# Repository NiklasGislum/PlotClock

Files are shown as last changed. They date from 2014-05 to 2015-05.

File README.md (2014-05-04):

PlotClock
=========

Fork of the plotclock optimized for better manfucaturability and for the available whiteboard markers.

* Larger material ring around screw holes for greater strength
* Larger holes for servo screws in the spacer plates.
* Claw now fits steadler whiteboard markers.
* M3 holes now accept 16 mm screws, because that what we had in stock.

TODO: 

* Go back to using filled shape for the servo-horn holes.
* Add text labels to each junction to make it easier to write an assembly manual.

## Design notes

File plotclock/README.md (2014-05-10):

plotclock
=========

plotclock

a clock that plots time

What you need
-------------
* Lasercutter or 3D Printer

* one Arduino (e.g. uno)

* three RC-Servos Mini (e.g. Tower Pro 9g)

* one whiteboard marker, dry eerasable (e.g. WB SL DRYWIPE MARKER)

* Screws, nuts, washers M3 and a tap for cutting M3.

Assembly
--------

See: http://www.thingiverse.com/thing:248009/#instructions

--

this actually is my first git project, so merging, forks etc. is still new to me and could take some time

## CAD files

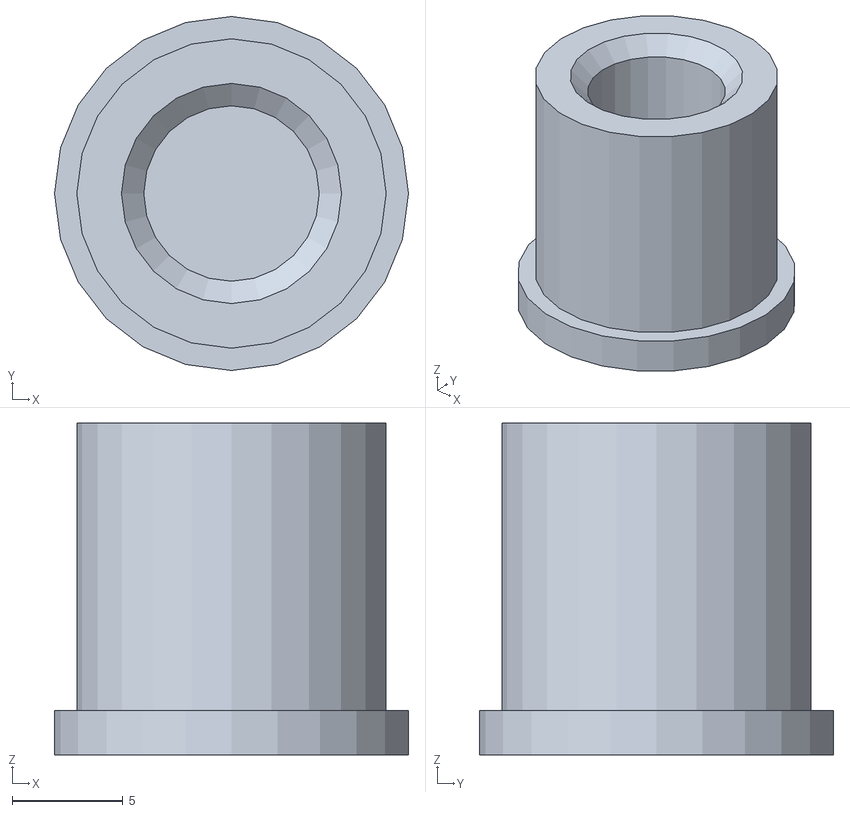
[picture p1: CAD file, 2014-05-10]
plotclock/swee.stl
16.0 x 16.0 x 15.0

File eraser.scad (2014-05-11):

difference(){
 union(){
  cylinder( r=7, h=8, $fn=100);
  cylinder( r=10, h=1, $fn=100);
  translate(v = [0, 0, 1]) {
  	cylinder( r1=10, r2=7, h=3, $fn=100);
  }
 }

 translate(v = [0, 0, 0.5]) {
  cylinder( r=2.25, h=8, $fn=100);
 }
 translate(v = [0, 0, 6]) {
  cylinder( r1=2.25, r2=6, h=3, $fn=100);
 }
}
 

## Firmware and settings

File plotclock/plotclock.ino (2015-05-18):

// Plotclock
// cc - by Johannes Heberlein 2014
// v 1.02
// thingiverse.com/joo   wiki.fablab-nuernberg.de
// units: mm; microseconds; radians
// origin: bottom left of drawing surface
// time library see http://playground.arduino.cc/Code/time 
// RTC  library see http://playground.arduino.cc/Code/time 
//               or http://www.pjrc.com/teensy/td_libs_DS1307RTC.html  
// Change log:
// 1.01  Release by joo at https://github.com/9a/plotclock
// 1.02  Additional features implemented by Dave:
//       - added ability to calibrate servofaktor seperately for left and right servos
//       - added code to support DS1307, DS1337 and DS3231 real time clock chips
//       - see http://www.pjrc.com/teensy/td_libs_DS1307RTC.html for how to hook up the real time clock 

// delete or mark the next line as comment if you don't need these
//#define REALTIMECLOCK    // enable real time clock

// delete or mark the next line as comment if you don't need these
#include <Stepper.h>
#define ALARM    // enable the alarm
#define SERIALOUTPUT // outputs the servor values to serial
// Create a file called calibration.h with the robot-specific values
#include "calibration.h"

/*
This is the content that your calibration.h file should have:
//#define CALIBRATION      // enable calibration mode

#define SERVOFAKTORLEFT 590
#define SERVOFAKTORRIGHT 600

// Zero-position of left and right servo
// When in calibration mode, adjust the NULL-values so that the servo arms are at all times parallel
// either to the X or Y axis
#define SERVOLEFTNULL 2320
#define SERVORIGHTNULL 1010


#define LIFT0 1150 // on drawing surface
#define LIFT1 825  // between numbers
#define LIFT2 725  // going towards sweeper

*/



// GPIO pins that the servos are connected to:
#define SERVOPINLIFT  6
#define SERVOPINLEFT  5
#define SERVOPINRIGHT 4

// lift positions of lifting servo
/*
#define LIFT0 1000 // on drawing surface
#define LIFT1 925  // between numbers
#define LIFT2 725  // going towards sweeper
*/

// speed of liftimg arm, higher is slower
#define LIFTSPEED 1500

// length of arms
#define L1 35
#define L2 55.1
#define L3 13.2

// origin points of left and right servo 
#define O1X 22
#define O1Y -25
#define O2X 48
#define O2Y -25

#define COLON 11

#define PARK_X 72
#define PARK_Y 42



#include <Time.h> // see http://playground.arduino.cc/Code/time 
#include <Servo.h>

#ifdef REALTIMECLOCK
// for instructions on how to hook up a real time clock,
// see here -> http://www.pjrc.com/teensy/td_libs_DS1307RTC.html
// DS1307RTC works with the DS1307, DS1337 and DS3231 real time clock chips.
// Please run the SetTime example to initialize the time on new RTC chips and begin running.

  #include <Wire.h>
  #include <DS1307RTC.h> // see http://playground.arduino.cc/Code/time    
#endif

#ifdef ALARM
	#include <TimeAlarms.h>
#endif

int servoLift = 1500;

Servo servo1;  // 
Servo servo2;  // 
Servo servo3;  // 

volatile double lastX = PARK_X;
volatile double lastY = PARK_Y;

 int servo1ValRad;
 int servo2ValRad;
 int servo3ValRad;

int last_min = 0;

void setup() 
{ 
#ifdef REALTIMECLOCK
  Serial.begin(115200);
  //while (!Serial) { ; } // wait for serial port to connect. Needed for Leonardo only

  // Set current time only the first to values, hh,mm are needed  
  tmElements_t tm;
  if (RTC.read(tm)) 
  {
    setTime(tm.Hour,tm.Minute,tm.Second,tm.Day,tm.Month,tm.Year);
    Serial.println("DS1307 time is set OK.");
  } 
  else 
  {
    if (RTC.chipPresent())
    {
      Serial.println("DS1307 is stopped.  Please run the SetTime example to initialize the time and begin running.");
    } 
    else 
    {
      Serial.println("DS1307 read error!  Please check the circuitry.");
    } 
    // Set current time only the first to values, hh,mm are needed
    setTime(19,38,0,0,0,0);
  }
#else  
  // Set current time only the first to values, hh,mm are needed
  setTime(10,01,0,0,0,0);
#endif

#ifdef ALARM
  Alarm.alarmRepeat(10, 8, 0, alarmAction);
#endif

#ifdef SERIALOUTPUT
  Serial.begin(9600);
#endif

  servoLift = LIFT0;
  lift(2);
  servo1.attach(SERVOPINLIFT);  //  lifting servo
  delay(1000); // Wait for the pen to be raised
  servo2.attach(SERVOPINLEFT);  //  left servo
  servo3.attach(SERVOPINRIGHT);  //  right servo
 
  lift(2);
  drawTo(PARK_X, PARK_Y);
  lift(0);

  delay(1000);
} 

void loop() 
{ 

  
#ifdef CALIBRATION
  // Servohorns will have 90° between movements, parallel to x and y axis

  drawTo(-3, 29.2);
  delay(500);
  drawTo(74.1, 28);
  delay(500);


#else 


  int i = 0;
  if (last_min != minute()) {

	  if (!servo1.attached()) servo1.attach(SERVOPINLIFT);
	  if (!servo2.attached()) servo2.attach(SERVOPINLEFT);
	  if (!servo3.attached()) servo3.attach(SERVOPINRIGHT);

    lift(0);

    hour();
    while ((i+1)*10 <= hour())
    {
      i++;
    }

    erase();
    lift(2);

    drawChar(5, 25, i, 0.9);
    drawChar(19, 25, (hour()-i*10), 0.9);
    drawChar(28, 25, COLON, 0.9);

    i=0;
    while ((i+1)*10 <= minute())
    {
      i++;
    }
    drawChar(34, 25, i, 0.9);
    drawChar(48, 25, (minute()-i*10), 0.9);
    lift(2);
    drawTo(PARK_X, PARK_Y);
    lift(0);
    last_min = minute();

    servo1.detach();
    servo2.detach();
    servo3.detach();
  }

#endif

} 

// Writing numeral with bx by being the bottom left originpoint. Scale 1 equals a 20 mm high font.
// The structure follows this principle: move to first startpoint of the numeral, lift down, draw numeral, lift up
void drawChar(float bx, float by, int num, float scale) {
  switch (num) {

  case 0:
    drawTo(bx + 12 * scale, by + 6 * scale);
    lift(0);
    bogenGZS(bx + 7 * scale, by + 10 * scale, 10 * scale, -0.8, 6.7, 0.5);
    lift(1);
    break;
  case 1:

    drawTo(bx + 3 * scale, by + 15 * scale);
    lift(0);
    drawTo(bx + 10 * scale, by + 20 * scale);
    drawTo(bx + 10 * scale, by + 0 * scale);
    lift(1);
    break;
  case 2:
    drawTo(bx + 2 * scale, by + 12 * scale);
    lift(0);
    bogenUZS(bx + 8 * scale, by + 14 * scale, 6 * scale, 3, -0.8, 1);
    drawTo(bx + 1 * scale, by + 0 * scale);
    drawTo(bx + 12 * scale, by + 0 * scale);
    lift(1);
    break;
  case 3:
    drawTo(bx + 2 * scale, by + 17 * scale);
    lift(0);
    bogenUZS(bx + 5 * scale, by + 15 * scale, 5 * scale, 3, -2, 1);
    bogenUZS(bx + 5 * scale, by + 5 * scale, 5 * scale, 1.57, -3, 1);
    lift(1);
    break;
  case 4:
    drawTo(bx + 10 * scale, by + 0 * scale);
    lift(0);
    drawTo(bx + 10 * scale, by + 20 * scale);
    drawTo(bx + 2 * scale, by + 6 * scale);
    drawTo(bx + 12 * scale, by + 6 * scale);
    lift(1);
    break;
  case 5:
    drawTo(bx + 2 * scale, by + 5 * scale);
    lift(0);
    bogenGZS(bx + 5 * scale, by + 6 * scale, 6 * scale, -2.5, 2, 1);
    drawTo(bx + 5 * scale, by + 20 * scale);
    drawTo(bx + 12 * scale, by + 20 * scale);
    lift(1);
    break;
  case 6:
    drawTo(bx + 2 * scale, by + 10 * scale);
    lift(0);
    bogenUZS(bx + 7 * scale, by + 6 * scale, 6 * scale, 2, -4.4, 1);
    drawTo(bx + 11 * scale, by + 20 * scale);
    lift(1);
    break;
  case 7:
    drawTo(bx + 2 * scale, by + 20 * scale);
    lift(0);
    drawTo(bx + 12 * scale, by + 20 * scale);
    drawTo(bx + 2 * scale, by + 0);
    lift(1);
    break;
  case 8:
    drawTo(bx + 5 * scale, by + 10 * scale);
    lift(0);
    bogenUZS(bx + 5 * scale, by + 15 * scale, 5 * scale, 4.7, -1.6, 1);
    bogenGZS(bx + 5 * scale, by + 5 * scale, 5 * scale, -4.7, 2, 1);
    lift(1);
    break;

  case 9:
    drawTo(bx + 9 * scale, by + 11 * scale);
    lift(0);
    bogenUZS(bx + 7 * scale, by + 15 * scale, 5 * scale, 4, -0.5, 1);
    drawTo(bx + 5 * scale, by + 0);
    lift(1);
    break;

  case COLON:
    drawTo(bx + 5 * scale, by + 15 * scale);
    lift(0);
    bogenGZS(bx + 5 * scale, by + 15 * scale, 0.1 * scale, 1, -1, 1);
    lift(1);
    drawTo(bx + 5 * scale, by + 5 * scale);
    lift(0);
    bogenGZS(bx + 5 * scale, by + 5 * scale, 0.1 * scale, 1, -1, 1);
    lift(1);
    break;
  }
}


void erase() {

  int y = PARK_Y;
  drawTo(PARK_X, y);  
  lift(0);
  
  drawTo(5, y);
  y = PARK_Y+10;
  
  while (y > 15) {
    drawTo(5, y);
    y -= 3;
    drawTo(5, y);       
    drawTo(PARK_X-15, y);       
    y -= 3;
    drawTo(PARK_X-15, y);       
  }

  drawTo(5, PARK_Y-10);       
  drawTo(PARK_X-10, PARK_Y);       
  
  drawTo(PARK_X, PARK_Y);       
}

void lift(char lift) {
  int targetLift;
  if (lift == 0) {
    targetLift = LIFT0;
  } else if (lift == 1) {
    targetLift = LIFT1;    
  } else {
    targetLift = LIFT2;
  }
  
  if (servoLift >= targetLift) {
      while (servoLift >= targetLift) {
        servoLift--;
        servo1.writeMicroseconds(servoLift);				
        delayMicroseconds(LIFTSPEED);
		servo1ValRad =map(servo1ValRad,600,2400,-90,90);
      } 
  } else {
      while (servoLift <= targetLift) {
        servoLift++;
        servo1.writeMicroseconds(servoLift);
        delayMicroseconds(LIFTSPEED);
		servo1ValRad = map(servo1ValRad, 600, 2400, -90, 90);
      }
  } 
}


void alarmAction()
{
	lift(2);
	drawTo(0,0);
	int numOfAlarms;

	for (int i = 0; i < numOfAlarms; i++)
	{
		drawTo(5, 5);
		delay(10000);
		drawTo(0,0);
	}
}

void bogenUZS(float bx, float by, float radius, int start, int ende, float sqee) {
  float inkr = -0.05;
  float count = 0;

  do {
    drawTo(sqee * radius * cos(start + count) + bx,
    radius * sin(start + count) + by);
    count += inkr;
  } 
  while ((start + count) > ende);

}

void bogenGZS(float bx, float by, float radius, int start, int ende, float sqee) {
  float inkr = 0.05;
  float count = 0;

  do {
    drawTo(sqee * radius * cos(start + count) + bx,
    radius * sin(start + count) + by);
    count += inkr;
  } 
  while ((start + count) <= ende);
}


void drawTo(double pX, double pY) {
  double dx, dy, c;
  int i;

  // dx dy of new point
  dx = pX - lastX;
  dy = pY - lastY;
  //path lenght in mm, times 4 equals 4 steps per mm
  c = floor(4 * sqrt(dx * dx + dy * dy));

  if (c < 1) c = 1;

  for (i = 0; i <= c; i++) {
    // draw line point by point
    set_XY(lastX + (i * dx / c), lastY + (i * dy / c));

  }

  lastX = pX;
  lastY = pY;
}

double return_angle(double a, double b, double c) {
  // cosine rule for angle between c and a
  return acos((a * a + c * c - b * b) / (2 * a * c));
}

void set_XY(double Tx, double Ty) 
{
  delay(1);

  double cLeft, a1Left;
  {
    // calculate triangle between pen, servoLeft and arm joint
    // cartesian dx/dy
    double dx = Tx - O1X;
    double dy = Ty - O1Y;
  
    // polar length (c) and angle (a1)
    cLeft = sqrt(dx * dx + dy * dy); // 
    a1Left = atan2(dy, dx); //
    double a2 = return_angle(L1, L2, cLeft);
  
    servo2.writeMicroseconds(floor(((a2 + a1Left - M_PI) * SERVOFAKTORLEFT) + SERVOLEFTNULL));
	//servo2ValRad = map((floor(((a2 + a1Left - M_PI) * SERVOFAKTORLEFT) + SERVOLEFTNULL)),600,2400,-90,90);
	//servo2ValRad = (floor(((a2 + a1Left - M_PI) * SERVOFAKTORLEFT) + SERVOLEFTNULL));
  }

  {
    // calculate joinr arm point for triangle of the right servo arm
    double a2 = return_angle(L2, L1, cLeft);
    double Hx = Tx + L3 * cos((a1Left - a2 + 0.621) + M_PI); //36,5°
    double Hy = Ty + L3 * sin((a1Left - a2 + 0.621) + M_PI);
  
    // calculate triangle between pen joint, servoRight and arm joint
    double dx = Hx - O2X;
    double dy = Hy - O2Y;
  
    double c = sqrt(dx * dx + dy * dy);
    double a1 = atan2(dy, dx);
    a2 = return_angle(L1, (L2 - L3), c);
  
    servo3.writeMicroseconds(floor(((a1 - a2) * SERVOFAKTORRIGHT) + SERVORIGHTNULL));
	//servo3ValRad = map((floor(((a1 - a2) * SERVOFAKTORRIGHT) + SERVORIGHTNULL)),600,2400,-90,90);
	//servo3ValRad = (floor(((a1 - a2) * SERVOFAKTORRIGHT) + SERVORIGHTNULL));
  }
#ifdef SERIALOUTPUT
  Serial.println(String(servo1ValRad) + ";" + String(servo2ValRad) + ";" + String(servo3ValRad));
#endif
}

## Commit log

2014-05-10 Moved the code to a directory that wants to work
    [swee.stl]
2014-05-10 Added ignore file for the calibration file
2014-05-10 Added eraser scad
    [eraser.scad]
2014-05-10 Fixed calibration mode
2014-05-10 Added eraser model
    [eraser.scad]
2014-05-11 Made the eraser a bit higher and deeper to take the load off the tip
    [eraser.scad]
2015-05-18 -- Made preperations for a physical alarm -- Output servor values to serialport for use in Blender
